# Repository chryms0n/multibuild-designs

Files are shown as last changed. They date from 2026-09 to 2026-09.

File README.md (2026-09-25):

# multibuild-designs

Custom 3D-printable parts for the [MultiBuild](https://multibuild.io/) organization system:
tool holders that mount on the **MultiBoard** grid, and bins for **MultiBin**.

Models are written as Python code with [build123d](https://github.com/gumyr/build123d)
and exported as STL/STEP for slicing.

Printed on a Bambu Lab A1 in PLA.

## Layout

| Path | Contents |
| --- | --- |
| `lib/` | Shared geometry: MultiBoard mounting interface, MultiBin dimensions |
| `models/multiboard/` | One source file per board-mounted part |
| `models/multibin/` | One source file per bin |
| `exports/` | Generated STL/STEP files, ready for the slicer |

## Usage

```bash
pip install -r requirements.txt
python models/multiboard/<part>.py
```

Each model script writes its STL/STEP files and a preview image (`<part>.png`) to `exports/`.

## Parts

| Part | Script | Print files |
| --- | --- | --- |
| Caliper holder (150 mm vernier caliper, one MultiBoard large hole + anti-rotation peg) | `models/multiboard/caliper_holder.py` | `exports/caliper_holder.stl`, `exports/caliper_holder_peg.stl` |

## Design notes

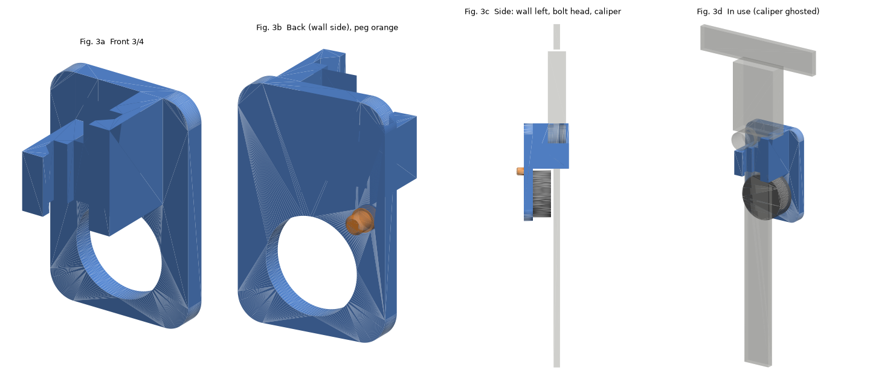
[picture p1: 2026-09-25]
exports/caliper_holder.png

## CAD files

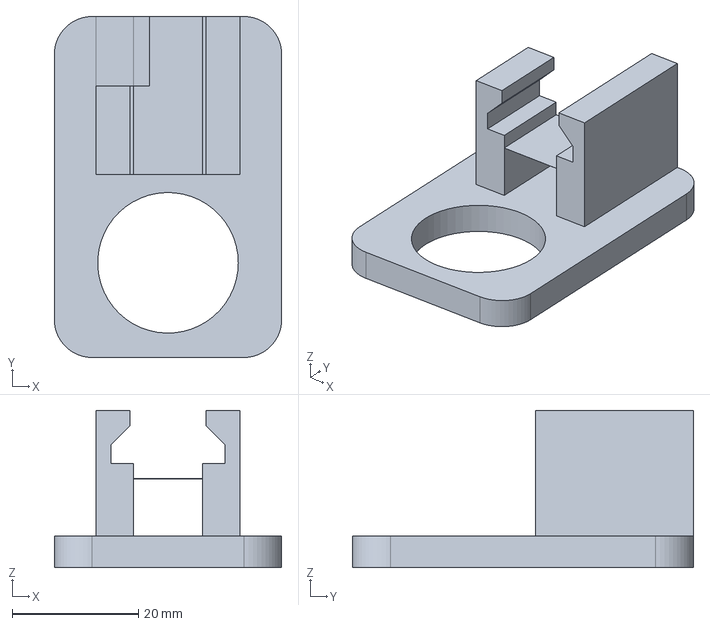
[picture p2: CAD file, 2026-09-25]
exports/caliper_holder.step
36.0 x 54.0 x 24.9 mm

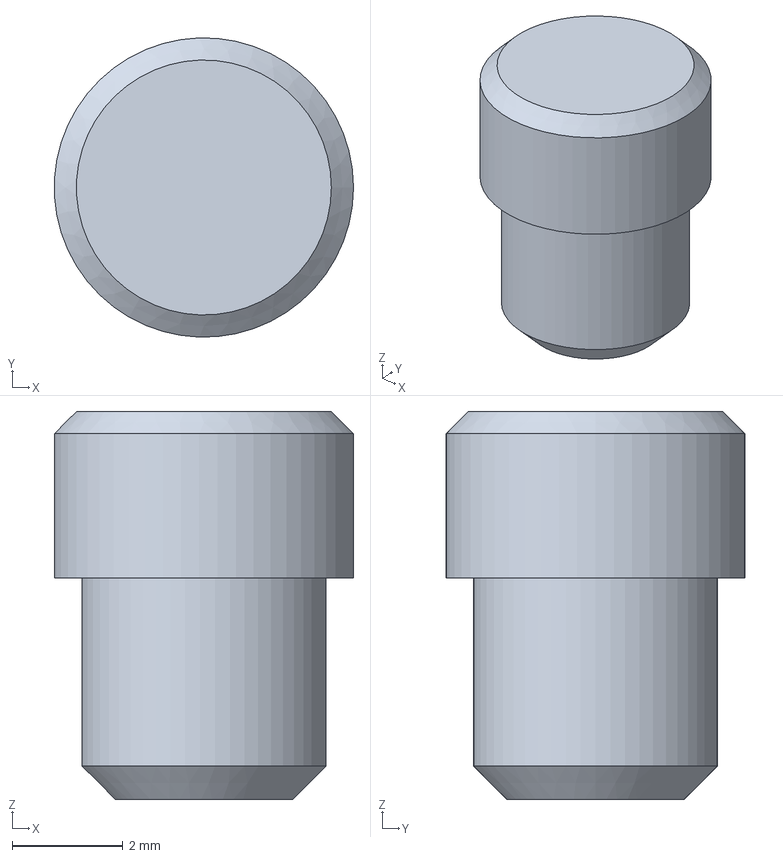
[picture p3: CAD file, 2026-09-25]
exports/caliper_holder_peg.step
5.39 x 5.40 x 7.00 mm

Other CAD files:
exports/caliper_holder.stl
exports/caliper_holder_peg.stl

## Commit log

2026-09-24 Add caliper holder for a MultiBoard large hole
    Short fork that hangs a 150 mm vernier caliper by its slider, fixed with one
    Large Thread bolt through the plate and a press-in peg in the adjacent small
    hole against rotation. Records the MultiBoard interface constants (with
    sources) in lib/multiboard.py and adds a matplotlib preview helper.
    Claude-Session: https://claude.ai/code/session_01CD2V2wsGFcRU9mQ5aLGBdR
    [caliper_holder.step, caliper_holder.stl, caliper_holder_peg.step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]
2026-09-25 Revise caliper holder after first test print
    - Wheel notch 15 -> 11 mm deep and wider, so the fine-adjust wheel rests on
    the notch floor and no longer rubs the back wall on the way in
    - Groove through the back wall for the depth-rod guide tab; the hollow behind
    it is narrowed to the groove width so nothing prints unsupported
    - Plate corner radius 2 -> 6 mm
    - Bolt through-hole 23.25 -> 22.25 mm, peg socket 4.6 -> 5.6 mm
    - Peg is now stepped: 5.4 mm press-fit part, 4.4 mm tile part
    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
    [caliper_holder.step, caliper_holder.stl, caliper_holder_peg.step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]
2026-11-03 Add shelf-pin wall hook with snap rod (draft)
    Plugs into two 5 mm holes through a 36 mm furniture panel. The upper rod is a
    split snap rod whose barbs catch behind the panel; the lower rod is a plain pin.
    12 mm wide J-hook, tapered back plate, printed on its side without supports.
    Claude-Session: https://claude.ai/code/session_01WabciB6gM6ScRT1MMXKUwq
2026-11-03 Strengthen shelf-pin hook for a ~10 kg backpack
    16 mm wide, 25 mm strap gap, 22 mm lip, 9 mm plate at the hook root, 10 mm
    bottom. The flat back face now runs straight down to the bottom of the hook
    (lower pivot, less pull on the snap rod). Rounded top edges, chamfered bed edges.
    Record the user's confirmation of panel thickness, through holes and hole spacing.
    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
2026-11-03 Add small shelf-pin hook variant
    Same rods, width and back plate; the J-hook is about half size (12.5 mm gap,
    11 mm lip). Hook size now lives in a HookShape dataclass in shelf_pin_hook.py so
    variants share the geometry code; the large hook's STL is unchanged.
    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
2026-11-03 Centre the rods in the shelf-pin hooks' width
    The rods were 6 mm off the hook's centre line (they sat on the print bed), so a
    load twisted the part. Both hooks now have the rods centred; they print with
    support under the rods only. The rod flats stay as the support contact face.
    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
2026-11-08 Raise the large shelf-pin hook; plate continues below it
    The hook moves up 11.5 mm on the back plate. The plate keeps reaching 19 mm
    below the lower rod as a 6 mm tail, so the pivot on the panel and the pull on
    the snap rod stay as before. HookShape gains an optional plate_bottom for this;
    the small hook is unchanged.
    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
2026-11-08 Add raised small shelf-pin hook
    The small hook moved 11.5 mm up the back plate, like the large one; the plate
    still reaches 9.75 mm below the lower rod, so the snap-rod pull is unchanged.
    The existing small hook stays as it is.
    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
2026-11-08 Add locking key for the shelf-pin hooks' snap rod
    A tapered blade (1.7 -> 1.3 mm) that goes into the 1.8 mm snap slot from behind
    the panel, so the barbed halves cannot be squeezed together. 16 mm long (covers
    the barbs plus 9.5 mm), with a 7 x 3 mm grip head. Fits all three hooks.
    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
